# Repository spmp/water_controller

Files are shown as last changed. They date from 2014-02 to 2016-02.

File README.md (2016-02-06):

Water Controller
================

The aim of this project is to control and monitor a water heating system.
This is currently a **Work in Progress**, and it is largely incomplete.

The project will consist of four main parts:

  1. An atmega328 MCU with a control system that directly interfaces with
     the water heater. It also operates over a serial interface to interact
     with a PC.

  2. A daemon running on the PC which can talk to the MCU. The daemon receives
     regular logging information from the MCU which it saves to a database.
     The daemon also allows various commands to be sent to the MCU.

  3. A web application that can display logs from the database, and can
     control the MCU via the daemon.
     
  4. A schematic and PCB artwork.

Currently only (1) is functional.

The _driveres_ for the project are in `AVR-lib`. At this stage I am (slowly) moving to github for issue tracking etc.

MCU
---

The project uses the Arduino Nano for both prototyping and target operation. To upload the code do the following:

 1. Plug in the MCU via USB to your computer. Check that `lsusb` shows the
    device, and that /dev/ttyUSB0 is writable (add your user to that device's
    group if not).

 2. Install the avr gcc toolchain. In Ubuntu/Debian, the packages you need
    (at least) are `avr-gcc`, `avr-libc`, and `avrdude` and their
    dependencies.

 3. Run `make` to compile the source, and `make upload` to compile and upload
    to the MCU via `/dev/ttyUSB*`. The program will start running immediately.

At present, the MCU reads data from the following inputs:

 * Pressure sensor (MPXV4006 I think...) via 12 bit I2C ADC (MPXV4006)
 * Temperature sensors (DS18B20) via OW to I2C (DS2482-100) (WIP)

These are sent over the serial interface to the PC along with a "timestamp" (the
number of seconds since the program started) at regular intervals.

To view the output, run `screen /dev/ttyUSB0 38400` (exit with `C-a k y`).

Logging daemon (logger.py)
--------------------------

This saves the data sent from the MCU to a sqlite3 database. Written in
Python3. To run it, just run

    $ ./logger.py

when the MCU is connected to the computer. The program will print out the
messages it recieves from the MCU, and also insert them into the database
`log_timeseries.db`. Type `Ctrl-C` or `Ctrl-D` to exit. You can view the
database directly using `sqlite3 log_timerseries.db`.

The logger should also have an interface for sending commands to the MCU. The
interface will be over TCP or a named pipe.

Web interface
-------------

The backend of the web layer reads from the sqlite3 database and displays
useful graphs on a web page. The graphs are rendered client-side using
jqplot, a jquery plugin. All of the javascript libraries are accessed over
cdn, meaning they don't have to be stored on the web server.

The backend is written in Python3, and uses the [Bottle web framework][bottle].
Bottle is a WSGI compliant framework, so it can be used with apache or nginx.
It can also run on its own using the builtin Python WSGIServer. This is the
current setup, and it can be run using

    $ web/webapp.py

where it serves the files to localhost:8080.

[bottle]: http://bottlepy.org/docs/stable/

The web page should also contain some commands to directly control the MCU.
These will be sent via the web backend to the logging daemon and from there
on to the MCU.

Circuit
-------

In brief: The Arduino nano plugs into the circuit board, reads its inputs from I2C, sending serial out via a MAX232. The heaters and pump are controlled via zero crossing triac driver and triacs. The filler solenoid is controlled via logic level fet. All outputs can be disabled, overwridden, or be controlled via MCU with a three position toggle switch. LED's indicate the output state, and the MCU flashes politely when operating. DC power is supplied by a 12V smps.

The circuit and artwork are in ```cad``` and ```eagle``` respectivly.

Issues
------
* The I2C driver needs a major upate which must happen in tandem with this (and all other dependent projects) to support a separate error state with recovery.
* If an I2C error in level is detected it must:
    1. Report 0mm
    2. Turn off heaters
    3. Turn off filler
    4. Turn off pump
    5. Raise a _level_ error flag in USART output
    
* If an error in temperature is detected it must:
    1. Report 0deg cent.
    2. Turn off heater
    3. Raise a _temperature_ error flag in USART output
    
Normal operation must continue once normal sensing is restored.

* Fill time detection and auto off. Sometimes the filler does not turn off correctl due to I2C errors or misreading. To avoid a flooded yard whilst on holiday a maximum fill time needs to be obeyed, taking into account a complete fill _with_ the pump on. If this time (`MAX_FILL_TIME`) is exceeded the filler must be disabled and not re-enabled unless done so manually via USART.

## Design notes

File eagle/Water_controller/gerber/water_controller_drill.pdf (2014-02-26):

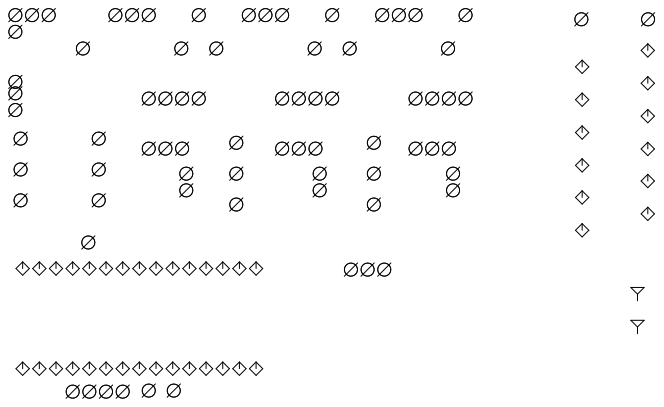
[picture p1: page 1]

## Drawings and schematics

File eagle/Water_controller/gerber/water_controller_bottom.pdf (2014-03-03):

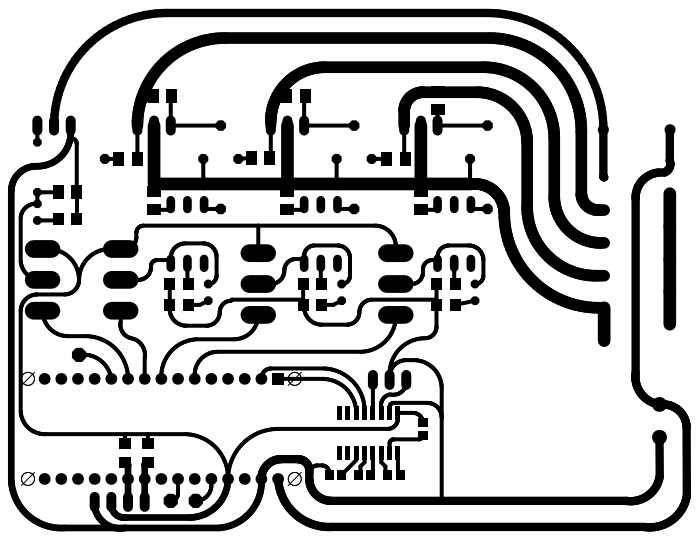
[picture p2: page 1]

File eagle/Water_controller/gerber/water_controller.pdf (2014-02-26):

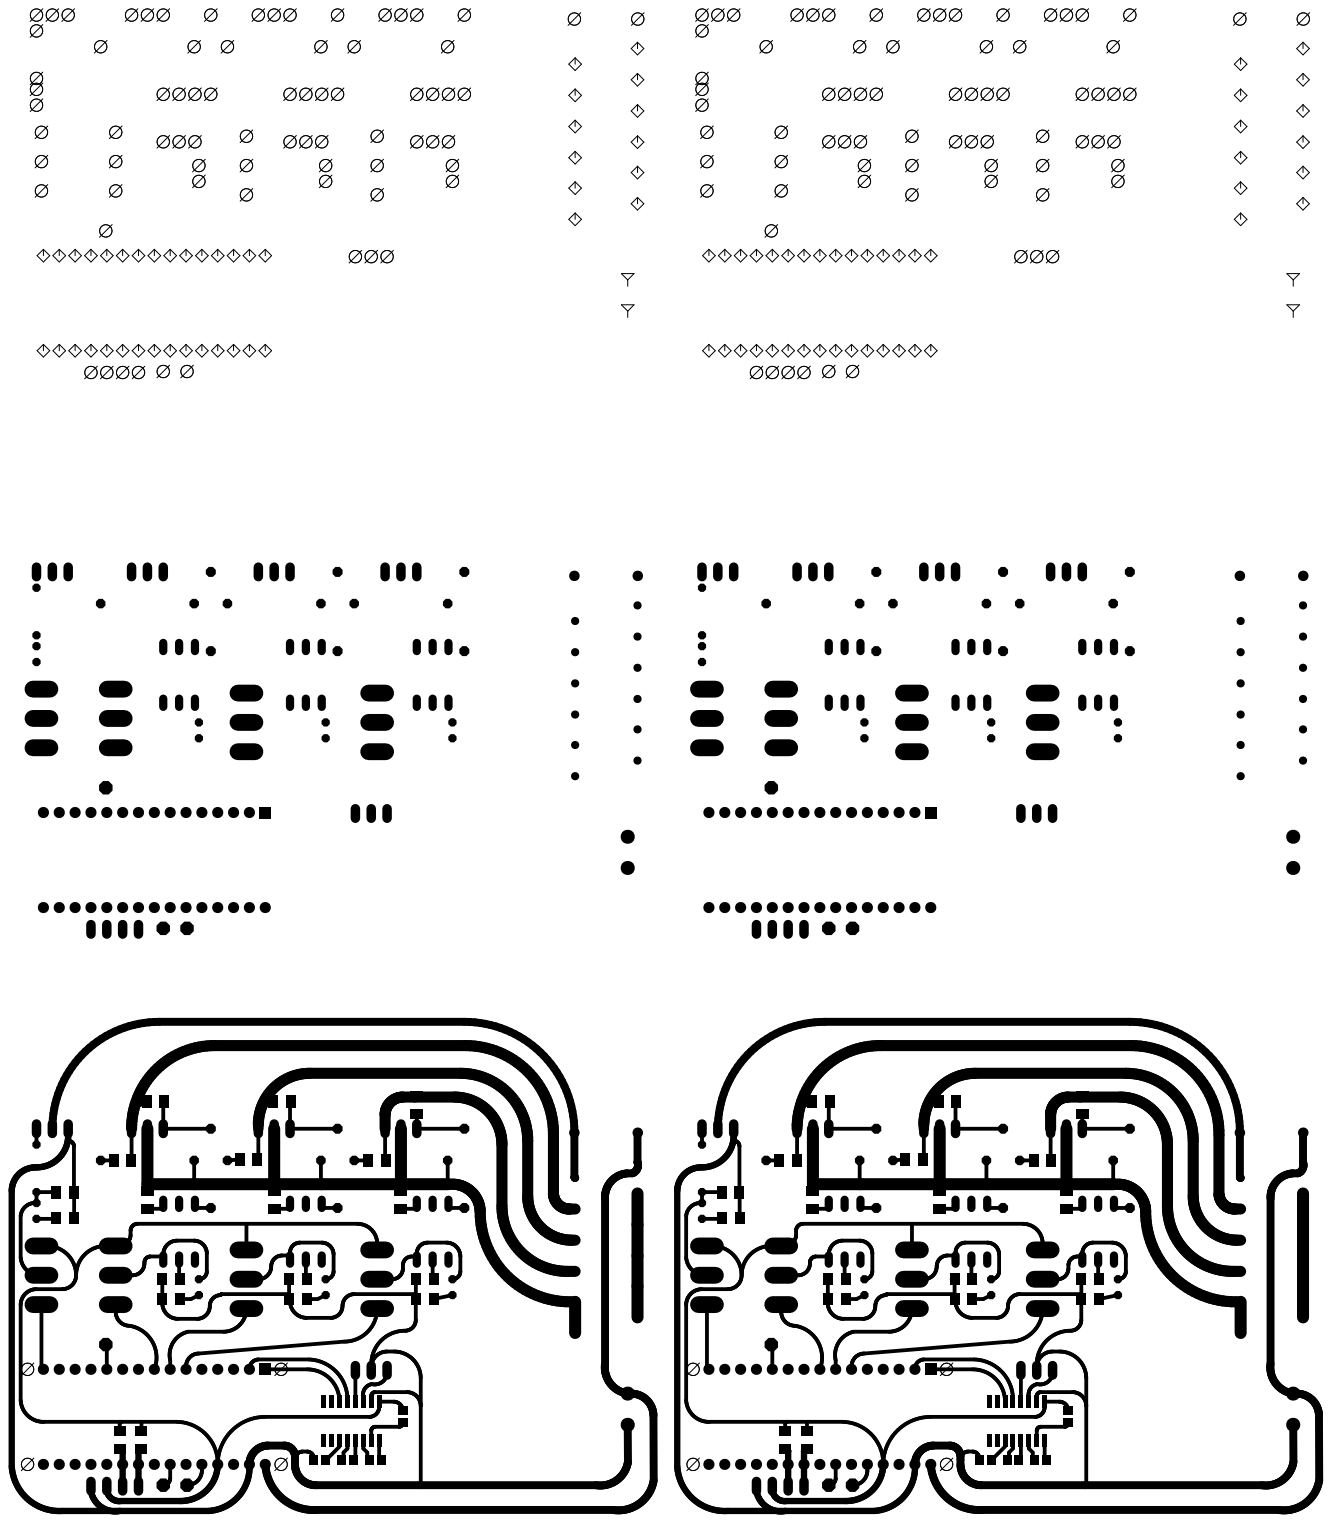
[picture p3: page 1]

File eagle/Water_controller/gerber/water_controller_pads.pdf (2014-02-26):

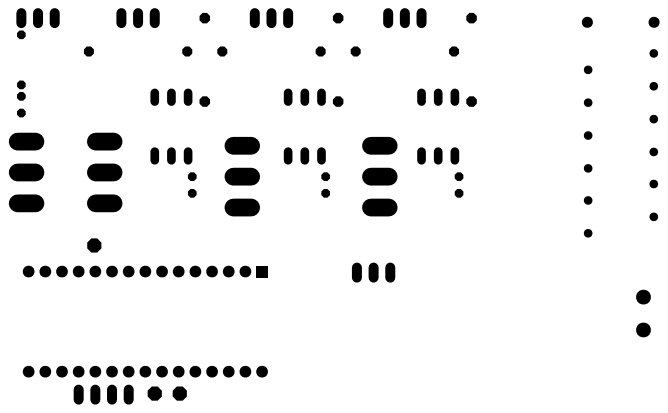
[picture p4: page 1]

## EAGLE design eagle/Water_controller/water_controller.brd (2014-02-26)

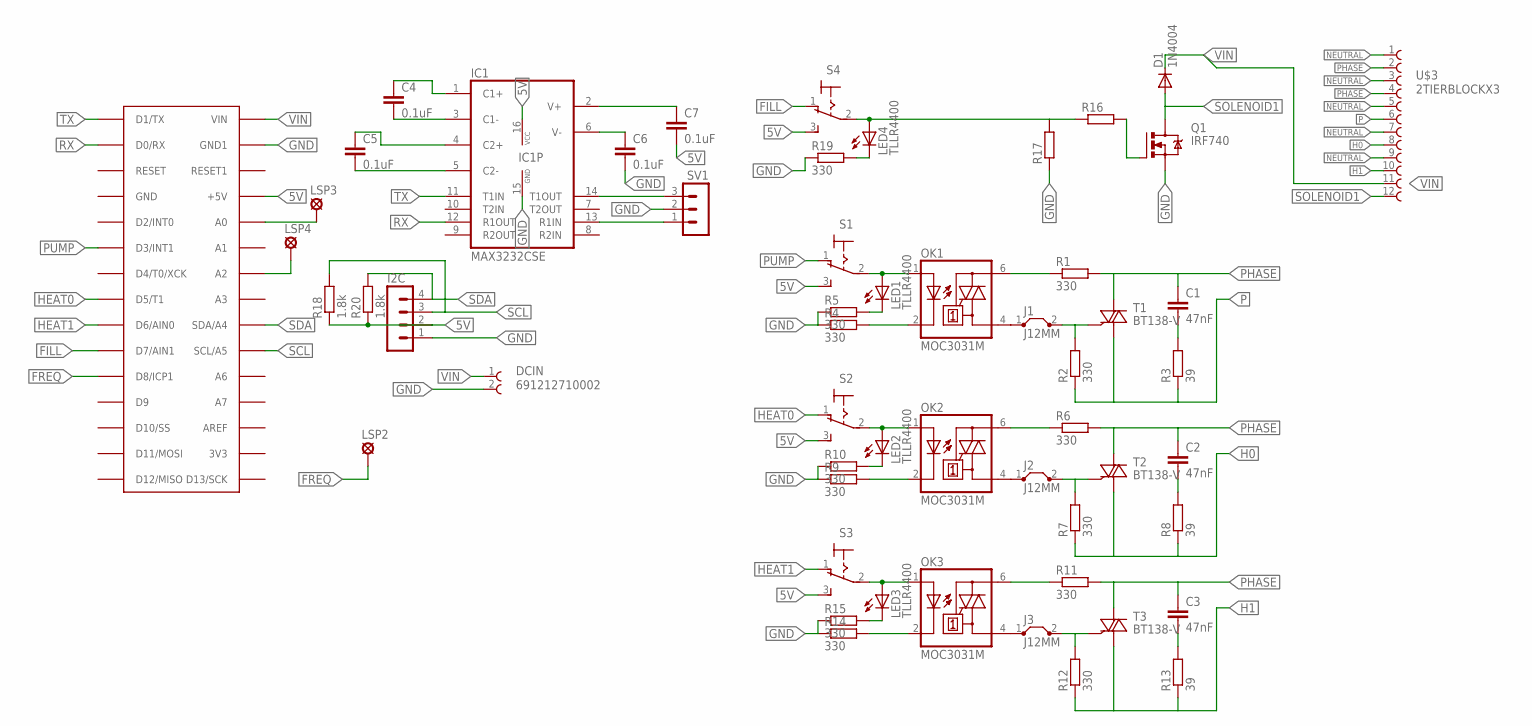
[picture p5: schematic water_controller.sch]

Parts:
C1, C2, C3: 47nF; C150-064X183
C4, C5, C6, C7: 0.1uF; C0805
D1: 1N4004; DO41-10
DCIN: 691212710002
I2C: MA04-1
IC1: MAX3232CSE; SO16
J1, J2, J3: J12MM; 12
LED1, LED2, LED3, LED4: TLLR4400; LED3MM
LSP2, LSP3, LSP4: LSP11
OK1, OK2, OK3: MOC3031M; DIL06; MPN MOC3063
Q1: IRF740; TO220BV
R1, R2, R6, R7, R11, R12: 330; M1206
R3, R8, R13: 39; M1206
R4, R5, R9, R10, R14, R15, R19: 330; R1206
R16: R-EU_0204/7; 0204/7
R17: R-EU_M1206; M1206
R18, R20: 1.8k; R1206
S1, S2, S3, S4: M9040P
SV1: MA03-1
T1, T2, T3: BT138-V; TO220BV
U$1: ARDUINONANO; PDIP-32
U$3: 2TIERBLOCKX3; 2TIERX3

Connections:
5V: C7.2, I2C.2, IC1.16 (VCC), R18.1, R20.1, S1.3 (S), S2.3 (S), S3.3 (S), S4.3 (S), U$1.+5V
FILL: S4.1 (O), U$1.D7 (D7/AIN1)
FREQ: LSP2.MP, U$1.D8 (D8/ICP1)
GND: C6.2, DCIN.2, I2C.1, IC1.15 (GND), Q1.S, R4.1, R5.1, R9.1, R10.1, R14.1, R15.1, R17.1, R19.1, SV1.2, U$1.GND1
H0: R7.1, R8.1, T2.T1 (A1), U$3.8
H1: R12.1, R13.1, T3.T1 (A1), U$3.10
HEAT0: S2.1 (O), U$1.D5 (D5/T1)
HEAT1: S3.1 (O), U$1.D6 (D6/AIN0)
unnamed: C1.2, R3.2
unnamed: C2.2, R8.2
unnamed: OK1.6 (A2), R1.1
unnamed: J1.2, R2.2, T1.G
unnamed: C4.2, IC1.3 (C1-)
unnamed: OK1.2 (C), R4.2
unnamed: LED1.A, OK1.1 (A), S1.2
unnamed: LED1.K (C), R5.2
unnamed: C4.1, IC1.1 (C1+)
unnamed: OK2.6 (A2), R6.1
unnamed: J2.2, R7.2, T2.G
unnamed: OK2.2 (C), R9.2
unnamed: LED2.A, OK2.1 (A), S2.2
unnamed: LED2.K (C), R10.2
unnamed: C3.2, R13.2
unnamed: OK3.6 (A2), R11.1
unnamed: J3.2, R12.2, T3.G
unnamed: OK3.2 (C), R14.2
unnamed: LED3.A, OK3.1 (A), S3.2
unnamed: LED3.K (C), R15.2
unnamed: C5.2, IC1.5 (C2-)
unnamed: Q1.G, R16.2
unnamed: C5.1, IC1.4 (C2+)
unnamed: LED4.A, R16.1, R17.2, S4.2
unnamed: LED4.K (C), R19.2
unnamed: C6.1, IC1.6 (V-)
unnamed: C7.1, IC1.2 (V+)
unnamed: J1.1, OK1.4 (A1)
unnamed: J2.1, OK2.4 (A1)
unnamed: J3.1, OK3.4 (A1)
unnamed: IC1.13 (R1IN), SV1.1
unnamed: IC1.14 (T1OUT), SV1.3
unnamed: LSP4.MP, U$1.A2
unnamed: LSP3.MP, U$1.A0
NEUTRAL: U$3.1, U$3.3, U$3.5, U$3.7, U$3.9
P: R2.1, R3.1, T1.T1 (A1), U$3.6
PHASE: C1.1, C2.1, C3.1, R1.2, R6.2, R11.2, T1.T2 (A2), T2.T2 (A2), T3.T2 (A2), U$3.2, U$3.4
PUMP: S1.1 (O), U$1.D3 (D3/INT1)
RX: IC1.12 (R1OUT), U$1.D0/RX
SCL: I2C.3, R18.2, U$1.A5 (SCL/A5)
SDA: I2C.4, R20.2, U$1.A4 (SDA/A4)
SOLENOID1: D1.A, Q1.D, U$3.12
TX: IC1.11 (T1IN), U$1.D1/TX
VIN: D1.C, DCIN.1, U$1.VIN, U$3.11

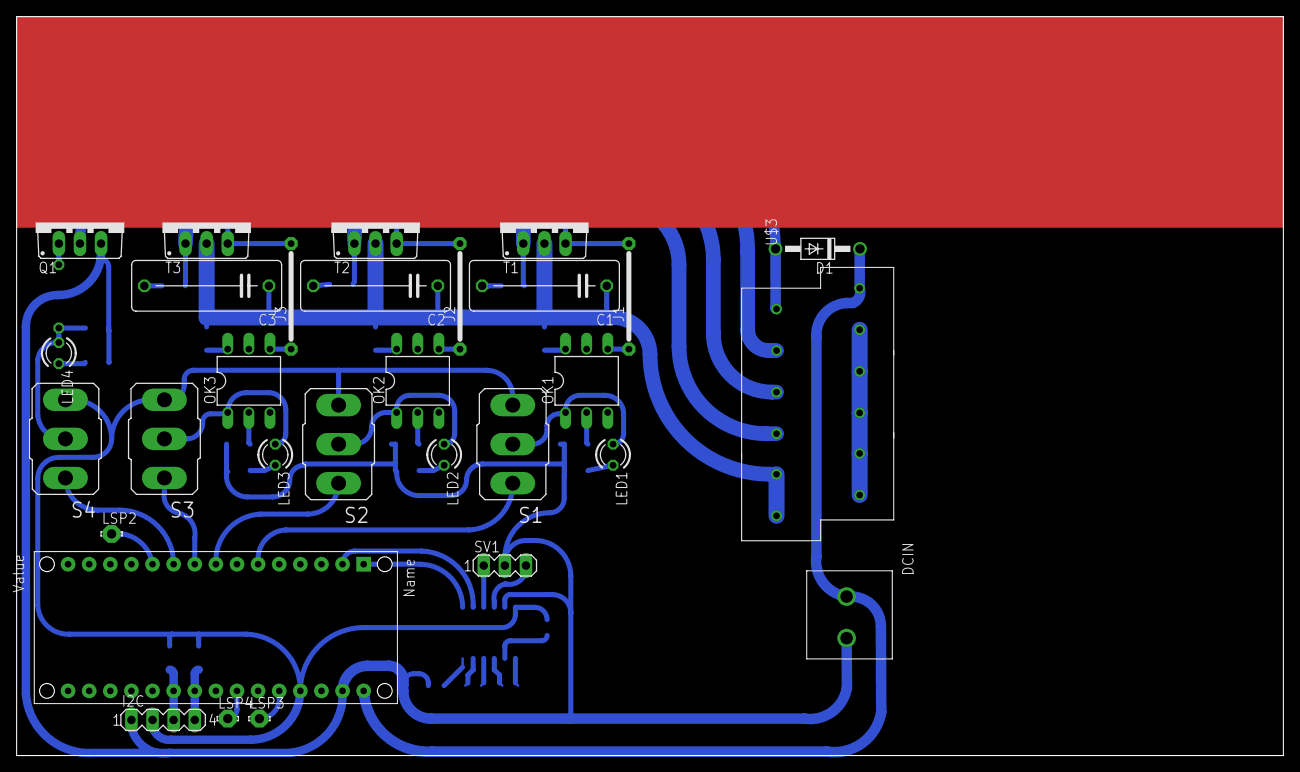
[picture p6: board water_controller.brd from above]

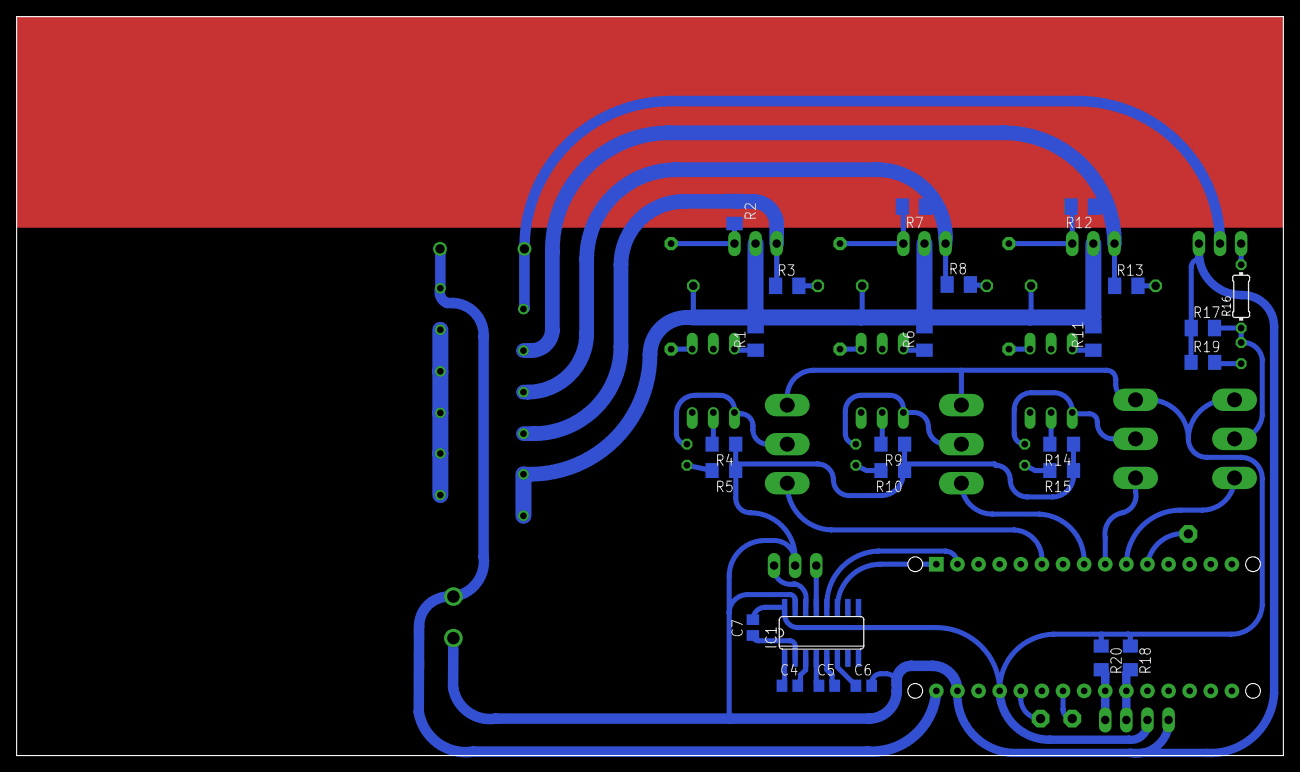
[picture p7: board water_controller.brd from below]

Board: 2 copper layers, 152.4 x 88.9 mm, 55 parts (25 on the bottom side), 52 nets.

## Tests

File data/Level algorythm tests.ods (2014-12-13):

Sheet: Sheet1
Checking Volume calculation algorythm |  |  |  | Time to hot calculations with proper volume and linear volme
Radius | 175 | Linear Factor | 0.5497787144 | DeltaT | 40000 | Scaling | 10
Length | 2000 |  |  | Cp | 4186
 |  |  |  | W | 3000
Level (mm) | Theta | Volume (L) | Linear | Real Volume | Linear approximation | Difference (minutes *10)
0 | 0 | 0 | 0 | 0 | 0 | 0
10 | 0.6793851523 | 1.5640290373 | 5.4977871438 | 1.4548945667 | 5.1141637742 | 36.5926920753
20 | 0.9655318467 | 4.3848937493 | 10.9955742876 | 4.0789256077 | 10.2283275484 | 61.4940194068
30 | 1.1884900654 | 7.9834272362 | 16.4933614313 | 7.4263614246 | 15.3424913226 | 79.1612989794
40 | 1.3794263079 | 12.1790031214 | 21.9911485751 | 11.3291793481 | 20.4566550968 | 91.2747574872
50 | 1.5503867466 | 16.8619723305 | 27.4889357189 | 15.6853813723 | 25.570818871 | 98.8543749867
60 | 1.7075486982 | 21.9545951779 | 32.9867228627 | 20.4226523144 | 30.6849826452 | 102.6233033078
70 | 1.854590436 | 27.3968321026 | 38.4845100065 | 25.4851420403 | 35.7991464194 | 103.1400437903
80 | 1.9939217485 | 33.1396704816 | 43.9822971503 | 30.8272579191 | 40.9133101936 | 100.8605227444
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

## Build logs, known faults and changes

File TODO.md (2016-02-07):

TODO
=========
for the
Solar hotwater controller
----

Reliability/Bugs
====
* Serial communications ceases, suspect I2C
  * Watchdog timer **Continued tests and not working!**
  * I2C comms that timeout
    * modify I2C routines to return status. If status is bad then disable associated
      hardware (i.e pump and filler) until a test proves them to be good.
    * Recheck status of all failed elements every _long_ time period

Features to add
====
* A reset flag that the daemon should set to see if its missed a reset
* I2C initialisation returns a status
* I2C initialisation (in 'hardware.c') checks for pressure sensor and follow
    similar pattern to temperature sensor - enabling/disabling pump/fill/heat
* Program over serial (Autoreset/manual reset?)
* EEPROM:
  * Saving of configuration periodically
  * Loading of configuration

Features to improve
====
* Reset level on fill-to-top to agreed greatest level. (maybe)
* Filler maximum time
* State limit checking code that takes into account failed readings
* Long time period checks of sensors if errors present.

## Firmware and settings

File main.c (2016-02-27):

#include <avr/io.h>
#include <avr/interrupt.h>
#include <avr/sleep.h>
#include <util/delay.h>

#include "hardware.h"

#include "analytics.h"
#include "state-machine.h"
#include "command.h"
#include "log.h"

#define VERSION "2.7.7"

// Watchdog and reset state.
/*
 * First, we need a variable to hold the reset cause that can be written before
 * early sketch initialization (that might change r2), and won't be reset by the
 * various initialization code.
 * avr-gcc provides for this via the ".noinit" section.
 */
uint8_t resetFlags __attribute__ ((section(".noinit")));

/*
 * Next, we need to put some code to save reset cause from the bootload (in r2)
 * to the variable.  Again, avr-gcc provides special code sections for this.
 */
void resetFlagsInit(void) __attribute__ ((naked))
                          __attribute__ ((section (".init0")));
void resetFlagsInit(void)
{
  /*
   * save the reset flags passed from the bootloader
   * This is a "simple" matter of storing (STS) r2 in the special variable
   * that we have created.  We use assembler to access the right variable.
   */
  __asm__ __volatile__ ("sts %0, r2\n" : "=m" (resetFlags) :);
}

uint8_t send_log = 0;

void long_timestep() {
    analytics_begin_flag = 1;
}

void once_per_second() {
    send_log = 1;
    PORTB ^= (1 << PORTB5); //Toggle LED
    if (timestamp == 0) {
        analytics_reset();
    }
}

void medium_timestep() {
    begin_state_machine_flag = 1;
}

int main() {    
    cli();
    init_hardware(&program[state_machine_program]);
    set_sleep_mode(SLEEP_MODE_IDLE);
    wd_reset();
    
    //TODO: Read settings from EEprom
    
    //Send initialisation message:
    send_string_p(PSTR("Rx Solar Hotwater Controller. V:"VERSION".\r\nJasper Aorangi/Brendan Bycroft 2014. Have a nice day, and a great shower 8): "));
    send_uint16(resetFlags);
    send_string_p(PSTR(" x\r\n"));

    // Watchdog reset status
    /*
    * check for the usual bits.  Note that the symnbols defined in wdt.h are
    * bit numbers, so they have to be shifted before comparison.
    */
/*
    if (resetFlags & (1<<WDRF))
    {
        send_string_p(PSTR(" Watchdog"));
        resetFlags &= ~(1<<WDRF);
    }
    if (resetFlags & (1<<BORF))
    {
        send_string_p(PSTR(" Brownout"));
        resetFlags &= ~(1<<BORF);
    }
    if (resetFlags & (1<<EXTRF))
    {
        send_string_p(PSTR(" External"));
        resetFlags &= ~(1<<EXTRF);
    }
    if (resetFlags & (1<<PORF))
    {
        send_string_p(PSTR(" PowerOn"));
        resetFlags &= ~(1<<PORF);
    }
    if (resetFlags != 0x00)
    {
        // It should never enter here
        send_string_p(PSTR(" Unknown"));
    }
    send_newline();
*/    
    
    //Set timer callbacks
    clock_set_long_time_callback(&long_timestep);
    clock_set_seconds_callback(&once_per_second);
    clock_set_medium_time_callback(&medium_timestep);
    
    //USART line handler
    usart_set_handle_char_string_from_serial(&handle_line);
    
    //Enable Global interrupts
    sei();

    if (STATEMACHINEENABLEDONSTART) {
        enable_state_machine();
    } else {
        disable_state_machine();        // Debugging. Will do this if MCUSR is not 0
    }
    if (LOGGINGENABLEDONSTART) {
        enable_logging();
    } else {
        disable_logging();              // Debugging
    }
    if (ANALYTICSENABLEDONSTART) {
        enable_analytics();
    } else {
        disable_analytics();              // Debugging
    }
        
    for (;;) {
        sleep_mode(); // blocked until after an interrupt has fired
        
        //USART
        while (num_in_serial_buffer()) { //check whether there is anything on the serial buffer, if there is, look at it
            handle_single_char_from_serial();
        }
        
        //Analytics
        if (analytics_begin_flag) {
            analytics_begin_flag = 0;
            analytics_run(&program[state_machine_program]);
        }
        
        //State machine 
        if (begin_state_machine_flag) {
            begin_state_machine_flag = 0;
            state_machine(&program[state_machine_program]);
        }
        
        //Logging
        if (send_log) {
            send_log = 0;
            log_to_serial(&program[state_machine_program]);
        }
        
        //Reset the watchdog
        wd_reset();
        
    }

    return 0;
}

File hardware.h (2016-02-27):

#pragma once
#include <avr/io.h>

/* AVR specifics */
#include "AVR-lib/clock.h"
#include "AVR-lib/ds18x20.h"
#include "AVR-lib/i2c_safe.h"
#include "AVR-lib/usart.h"
#include "AVR-lib/wd.h"
#include "state-machine.h"

/* DEBUGGING - i.e no environmental measurements */
// #define DEBUGGING

/* State machine defaults */
#define STATEMACHINEENABLEDONSTART 1
#define LOGGINGENABLEDONSTART 1
#define HEATERENABLEDONSTART 1
#define ANALYTICSENABLEDONSTART 1

/* Fill timer */
#define FILL_MAX_TIME 900
#define FILL_CHECK_TIME 60

/* Heater size */
#define HEATER_SIZE     2400L
#define SPECIFIC_HEAT_WATER 4186L

/* Clock and timing settings, time in 1/125's of a second*/
#define LONG_TIME_INTERVAL          CLOCK_TICKS_PER_SECOND*600L

/* Inputs */
#include "temperature.h"//Temperature reading
#include "level.h"      //Level and volume reading

/* Data buss settings   */
// USART
#define USARTBAUD       38400
// I2C
#define I2CSPEED        1000
// OW bit bang
#define OWPIN           PB0
#define OWIN            PINB
#define OWOUT           PORTB
#define OWDDR           DDRB
#define OW_USE_INTERNAL_PULLUP     0

// ds18x20 defines
#define DS18X20TEMPRES  DS18B20_12_BIT 

// IO defines:
#define ONBOARD_LED     PB5

#define OUTPUT_PORT     PORTD
#define INPUT_PORT      PIND
#define DIRECTION_REG   DDRD
#define PUMP_PIN        PD3
#define FILL_PIN        PD7
#define HEAT1_PIN       PD5
#define HEAT2_PIN       PD6

/* Initialise all hardware relevant to the project, usart, i2c, clock, external
 * sensors, Everyting!
 * One call to rule them all */
void init_hardware(struct Program *program);

/* Initialise I/O ports on the AVR */
void init_io_ports(void);

/* Hardware states */
uint8_t pump_state(void);
uint8_t fill_state(void);
uint8_t heater_state(void);

/* Set hardware states */
void pump_set(uint8_t state);
void fill_set(uint8_t state);
void heater_set(uint8_t state);

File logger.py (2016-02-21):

#!/usr/bin/python3

"""
data in: [timestamp, metric, value]

basically just dump that into a sqlite3 table.
"""

import sqlite3
import pyuv
import sys
import os
import serial
import signal
import time
import termios
import fcntl
import struct
import re
import datetime

class Logger:
    def __init__(self, dbname):
        print("Initialising logger database")
        
        self.conn = sqlite3.connect(dbname)
        self.cur = self.conn.cursor()

        #self.cur.execute("""
            #create table if not exists source (
                #name varchar(20)
            #)""")

        self.cur.execute("""
            create table if not exists hotwaterdata (
                time timestamp,
                temperature real,
                level real,
                volume real,
                pumpState integer,
                fillState integer,
                heatState integer,
                tth real
            )""")
        
    #def secondsConvertHMS(self, seconds):
        
        
    def add_data_point(self, timestamp, temperature, level, volume, pumpState,
                       fillState, heatState, tth):
        print("adding", timestamp, temperature, level, volume, pumpState,
              fillState, heatState, tth, "to db")
        self.cur.execute(
            'insert into hotwaterdata values (?, ?, ?, ?, ?, ?, ?, ?)', 
            (timestamp, float(temperature), float(level), float(volume), 
             int(pumpState), int(fillState), int(heatState))
        )

        self.conn.commit()

    def add_from_string(self, st):
        rx = "l\s+(?P<time>\d+)\st\s(?P<temperature>\d+) l (?P<level>\d+) v (?P<volume>\d+) p (?P<pump>\d) P \d f (?P<fill>\d) F \d h (?P<heat>\d) H \d OP \d+ T2H (?P<tth>\d+)"
        m = re.match(rx, st)
        if m is None:
            print("unable parse data_point:", st)
            return
        self.add_data_point(
            m.group('time'), m.group('temperature'), m.group('level'),
            m.group('volume'), m.group('pump'), m.group('fill'),
            m.group('heat'))


if __name__ == '__main__':
    l = Logger('log_timeseries.db')
    '''
    l.add_from_string(b"a 1234 14000 800")
    l.add_from_string(b"a 1235 14200 700")
    l.add_from_string(b"a 1236 13000 600")
    l.add_from_string(b"a 1237 14003 800")
    exit()
    '''

    loop = pyuv.Loop.default_loop()

    ser = serial.Serial()
    ser.port = '/dev/ttyUSB0'
    ser.baudrate = 38400
    ser.open()
    
    print("Serial port opened ", file=sys.stderr)

    tty_atmega = pyuv.TTY(loop, ser.fileno(), True)
    tty_stdin = pyuv.TTY(loop, sys.stdin.fileno(), True)
    tty_stdout = pyuv.TTY(loop, sys.stdin.fileno(), False)
    mybuf = b''

    def listen_atmega(tty, data, error):
        global mybuf

        mybuf += data.replace(b'\x00', b'')

        partial_lines = mybuf.split(b'\r\n')
        mybuf = partial_lines[-1]

        for line in partial_lines[:-1]:
            l.add_from_string(line)

        # tty_stdout.write(data)

    def listen_stdin(tty, data, error):
        if data is None or data == b"exit":
            loop.stop()
        else:
            tty_stdout.write(data)

    def listen_signal(handle, signum):
        print()
        loop.stop()

    tty_atmega.start_read(listen_atmega)
    tty_stdout.start_read(listen_stdin)

    signal_h = pyuv.Signal(loop)
    signal_h.start(listen_signal, signal.SIGINT)

    loop.run()

    ser.close()
    tty_stdout.close()
    tty_stdin.close()

    pyuv.TTY.reset_mode()
    l.cur.close()

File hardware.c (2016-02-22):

#include "hardware.h"

void init_hardware(struct Program *program) {
    struct Settings *settings = &program->settings;
    
    wd_reset();
    WD_SET(WD_OFF);
    // Initialise clock
    long_time_interval = LONG_TIME_INTERVAL;
    init_clock();
    // Initialise USART with speed USARTBAUDbaud
    init_usart(USARTBAUD, F_CPU);
    // Initilise I^2C with speed I2CSPEED
    i2c_init(I2CSPEED, F_CPU);
    // Initialise DS18X20 devices
    send_string_p(PSTR("DS18X20 initialising: "));
    if (ds18x20_init(DS18X20TEMPRES) == 0) {
        send_string_p(PSTR("Success, "));
        send_string_p(PSTR("The number of sensors is: "));
        send_uint8(ds18x20nSensors);
        send_newline();
        // enable the heater
        if (HEATERENABLEDONSTART) {
            settings->heater_enable = 1;
        }
    } else {
        send_string_p(PSTR("Failure"));
    }
    send_newline();
    // Initialise IO ports
    init_io_ports();
    // Set watchdog timer
    WD_SET(WD_RST,WDTO_4S);
}

void init_io_ports(void ) {
    
    //Set Internal LED pin to output
    DDRB |= (1 << ONBOARD_LED);
    
    //Set data direction for outputs
    DIRECTION_REG |= (1<<PUMP_PIN);
    DIRECTION_REG |= (1<<FILL_PIN);
    DIRECTION_REG |= (1<<HEAT1_PIN);
    DIRECTION_REG |= (1<<HEAT2_PIN);
    
//     DIRECTION_REG |= (1<<PUMP_PIN) & (1<<FILL_PIN) & (1<<HEAT1_PIN) & (1<<HEAT2_PIN);
    //Set outputs OFF
    OUTPUT_PORT &= ~((1<<PUMP_PIN) | (1<<FILL_PIN) | (1<<HEAT1_PIN) | (1<<HEAT2_PIN));

}


/* Get hardware states */
uint8_t pump_state(void) {
    return ((INPUT_PORT & (1<<PUMP_PIN)) == (1<<PUMP_PIN));
}
uint8_t fill_state(void) {
    return ((INPUT_PORT & (1<<FILL_PIN))==(1<<FILL_PIN));
//     return ((INPUT_PORT & (1<<FILL_PIN)) == (1<<FILL_PIN));
}
uint8_t heater_state(void) {
    if ((INPUT_PORT & (1<<HEAT1_PIN)) == (1<<HEAT1_PIN))
        return 1;
    else if  ((INPUT_PORT & (1<<HEAT2_PIN)) == (1<<HEAT2_PIN))
        return 1;
    else
        return 0;
    
//     return ( (INPUT_PORT & ((1<<HEAT1_PIN) | (1<<HEAT2_PIN))) == ((1<<HEAT1_PIN) | (1<<HEAT2_PIN)));
}

/* Set hardware states */
void pump_set(uint8_t state) {
    if (state == 1) {   // Set bit
        OUTPUT_PORT |= (1<< PUMP_PIN);
    }
    else { // Clear bit
        OUTPUT_PORT &=  ~(1<<PUMP_PIN);
    }
}

void fill_set(uint8_t state) {
    if (state == 1) {   // Set bit
        OUTPUT_PORT |= (1<< FILL_PIN);
    }
    else { // Clear bit
        OUTPUT_PORT &=  ~(1<<FILL_PIN);
    }
}

void heater_set(uint8_t state) {

    if (state == 1) {   // Set bits
        OUTPUT_PORT |= (1<< HEAT1_PIN);
        OUTPUT_PORT |= (1<< HEAT2_PIN);
    }
    else { // Clear bits
        OUTPUT_PORT &=  ~(1<<HEAT1_PIN);
        OUTPUT_PORT &=  ~(1<<HEAT2_PIN);
    }
}

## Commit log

2013-11-02 Add clock using timer/counter 2
2013-11-02 log ultrasonic & analog inputs to serial with timestamp
2013-11-02 simplify the ultrasonic distance measure
    The ultrasonic measurer now uses a single I/O pin (PORTB0/ardiuno digital 8)
    and a single interrupt (TIMER1_CAPT). When the ultrasonic sensor is not in
    use, TIMER1 is free for use in other parts of the application.
2013-11-30 Modified ADC read_analog for the case of pin 8 being internal temp. Spun off ADC stuff to adc.{c,h} Added very basic frequqncy measurement using 16 input capture timer Modified main - removed ultraso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
2013-12-08 Cleaned up as per *useful* comments. Added temperature related things. Maybe fixed frequency counter.
    [main.c]
2014-01-14 Levels and things, usart recieve and parse. Hardware will change
    [Pressure-Calibration.ods]
2014-01-20 Hardware: Schematic and PCB artwork done.
    [water_controller.brd, water_controller.sch, water_controller_1.SchDoc]
2014-02-18 i2c working with safe high level commands -- still need to find a way to break out of read_ack and read_nak while loop. Logging in separate folder. The idea of a config.h not sure how to impliment wi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
    [Pressure-Calibration.ods]
2014-02-18 Fixed dependency issues, some more stuff in command to test temperature probe.. all good. Need to get this whole struct input blah thing sorted so can get some good log messages.. Anyone want to fini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
    [command.c, main.c]
2014-02-21 Defined two more time periods: medium and fast, set state machine to run in medium tome perod, and separated USART, statemachine and logging, such that they are indipendent and USART and logging are 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
    [water_controller.brd, water_controller.sch]
2014-02-26 Wow, a Version 1.0alpha! Should be a working system _when_ program is populated with values... still to be done. Lots and lots to do... oh so much for a project that was supposed to take two weeks. N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
    [pressure-sensor-I2C-breakout.brd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]
2014-03-03 A working version with no 'state machine' for now. Added new functions to usart for uint32 and half uint32. Changed uint and i2c_safe init such that speed/baude and f_cpu are parameters. Changed the 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
    [command.c, hardware.c, hardware.h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]
2014-03-03 loads of floating point stuff sorted, volume and level fixed with zeroing routine. Fill routine faulty. redo with a ton of if thens
    [command.c, hardware.c, level.c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]
2014-03-06 Stuff, and the attempt to have multiple programs as program[], failing to initialise the programs so will revert on the next commit. Floating point done. Progmem done, hence USART menu (command.c) do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
    [command.c, level.c, main.c]
2014-08-12 Fixing broken heater logic. Clunky but obvious code
    [pressure-sensor-I2C-breakout.sch]
2014-08-13 fixed a lot of the temperature and heating stuff. Linearly approximating volume to avoid floating point
    [command.c, level.c]
2014-08-13 Test of various level/volume/heating related stuff.
    [Level algorythm tests.ods]
2014-08-15 moving to another computer. Need to fix probe.. again
2014-08-18 Added basic morning fill logic. Updated I2C address of one temperature sensor
2014-08-19 Recalibrate level sensor, revert Volume to floating point version
    [Level algorythm tests.ods]
2014-09-08 BaaBaaBlacksheep: Add watchdog initialisation and reset (after logging message). Add initialisation serial string.
    [hardware.c, hardware.h, main.c]
2014-09-08 Attempting to fix watchdog lockout
    [hardware.c, main.c]
2014-09-10 Fixed overflow in temperature by increasing size of read_AT30TSE758 to int32, whilst keeping temperature at uint16 as assue its not negative. Note there is a multiplication by 125 in read_AT30TSE758,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
2014-10-08 Rudimentary watchdog reset after 4S implimented. Added variable 'mcusr_mirror' in attempt to catch reset source, not working, or else always 0
    [command.c, hardware.c, main.c]
2014-10-09 Added proper reset testing using Optiboot internals 'r2'. ABout to start breaking IIC
    [main.c]
2014-10-09 Properly made safe the i2c routines with uint16 counters. Need to add failure mode detection...
2014-11-03 Fixing temperature issues. Signed and unsignedmake clean && make && make upload! Changed temperature to unsigned 16bit, so is Cx100
    [command.c, hardware.h, main.c]
2014-12-02 New temperature sensors and more stuff
2014-12-13 command and pressure sensor calibration mk II
    [Level algorythm tests.ods]
2014-12-13 Update level sensor for new one ... again, and remove temperature sensor 1 wwhich has failed in hardware...again
    [Level algorythm tests.ods]
2016-02-07 Updated heaps of stuff to use new temperature sensor. Temperature is now a int32 throughout.
2016-02-08 make timetoHot more explicit. Fix terminal output for temperature. Add verion define and incriment
    [command.c, main.c]
2016-02-19 Added a maximum fill time check with associate error register and 'setters and getters' from command
    [command.c, hardware.h, main.c]
2016-02-19 Fix 'howlong' calculation. Add debugging support, i.e manually enter temperature with 'T' and level with 'l'
    [command.c, hardware.h, main.c]
2016-02-21 First cut of cumulative energy implimentation
2016-02-22 Tested anaytics with correct timezone. Fixed analytics enable logic
    [command.c, hardware.c, hardware.h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]
2016-02-27 Updated and fixed fill testing, will now error if level does not increase.
    [hardware.h, main.c]

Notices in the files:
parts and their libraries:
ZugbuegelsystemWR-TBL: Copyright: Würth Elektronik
